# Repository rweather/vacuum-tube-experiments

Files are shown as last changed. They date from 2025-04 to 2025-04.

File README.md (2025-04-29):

Vacuum Tube Experiments
=======================

This repository collects up a number of experiments with making
vacuum tubes do interesting things at low voltage.

Many thanks to David Lovett a.k.a Usagi Electric for showing that it
was possible to operate vacuum tubes (or "valves" as we call them in
Australia) at low voltage and get useful work out of them.

## Blinky with two 6AU6 pentodes

The simplest thing to do with vacuum tubes is blink LED's!  Henri Abraham and
Eugene Bloch invented an
<a href="https://en.wikipedia.org/wiki/Multivibrator">astable multivibrator oscillator</a>
based on two triodes during World War I.
<a href="https://ik1zyw.blogspot.com/2022/01/abraham-bloch-valve-led-multivibrator.html">The author of this blog post</a>
showed how to make a simple Abraham-Bloch blinky that could operate down to
9V using the tubes they had available.

I adapted the circuit for two 6AU6's operating at 12V with the heaters
hooked up in series to give them 6V each.  That way I only needed a single
12V supply.  I added some blue LED's mounted underneath the tubes for extra
bling, but they are optional.

Here is the schematic (click for a PDF version):

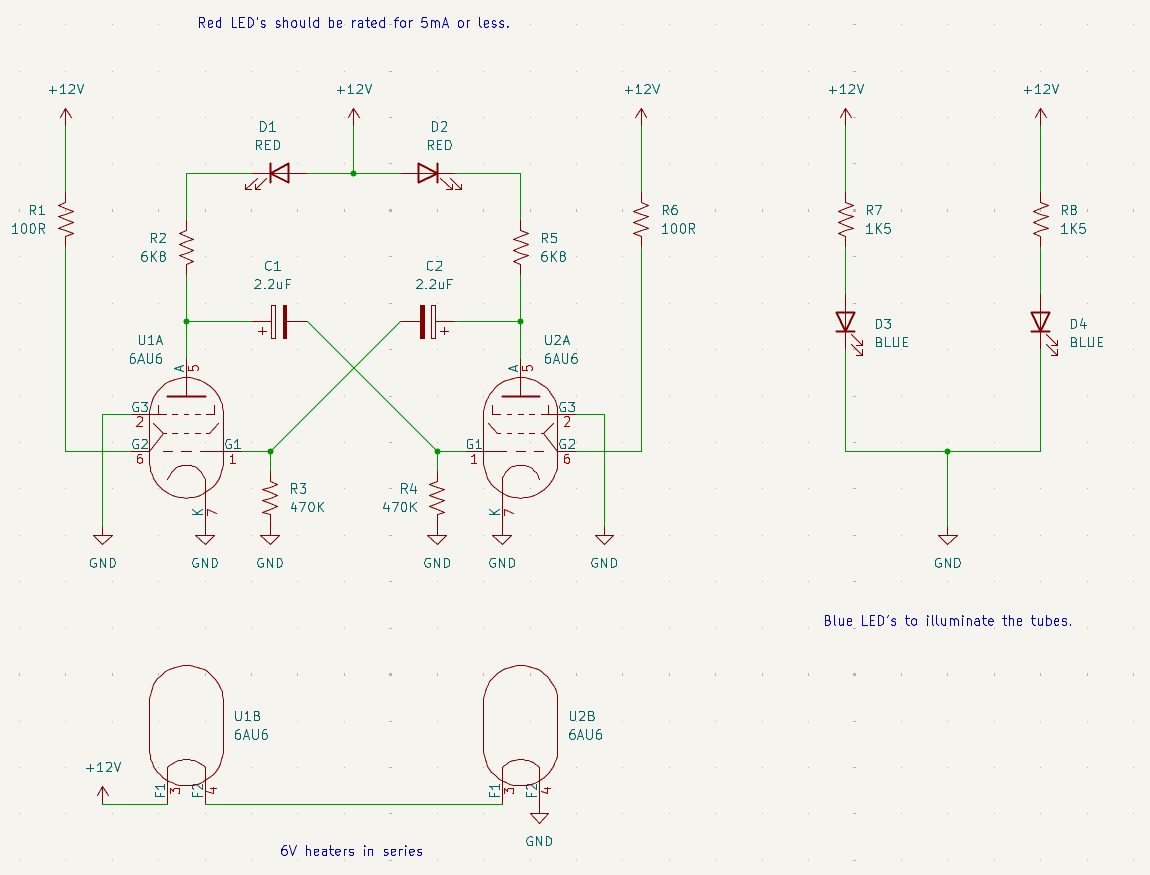
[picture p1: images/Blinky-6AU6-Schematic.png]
Blinky 6AU6 Schematic


Garden variety red LED's are rated for 15mA to 20mA and will be very dimly lit
with this circuit.  I recommend using red LED's that are rated for less than
5mA, ideally 2mA or less.

The period is about one second, spending half a second on each LED during the
blink cycle.  It takes about 5-10 seconds for the tubes to warm up, during
which time the LED's act a little weird.  It eventually sorts itself out.
The circuit is very sensitive - touching the components can change the blink
rate due to the impedance of the human body!

To adjust the blink rate, easiest is to change the value of C1 and C2 to
something higher or lower.  Alternatively, change R3 and R4.  Lower values
will blink faster.

I initially prototyped the circuit on a breadboard, and then soldered
up a real one on veroboard.  Here is what the real one looks like:

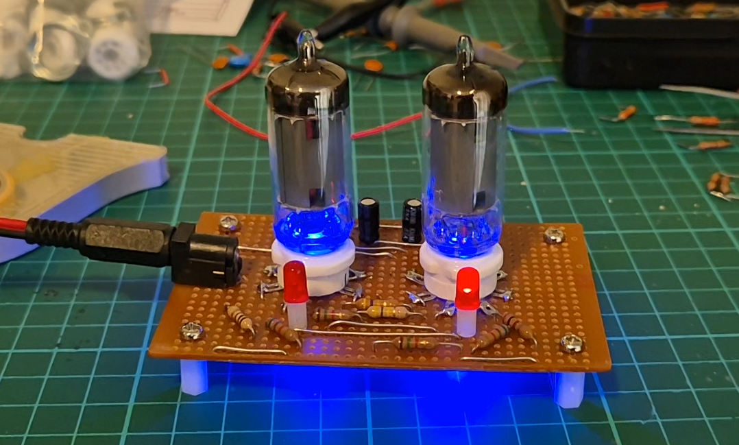
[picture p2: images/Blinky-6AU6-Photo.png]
Blinky 6AU6 Photo


## Blinky with a 6DJ8 dual triode

Can we do a blinky with one tube?  Yes we can!  The following schematic
uses a 6DJ8 dual triode (click for a PDF version):

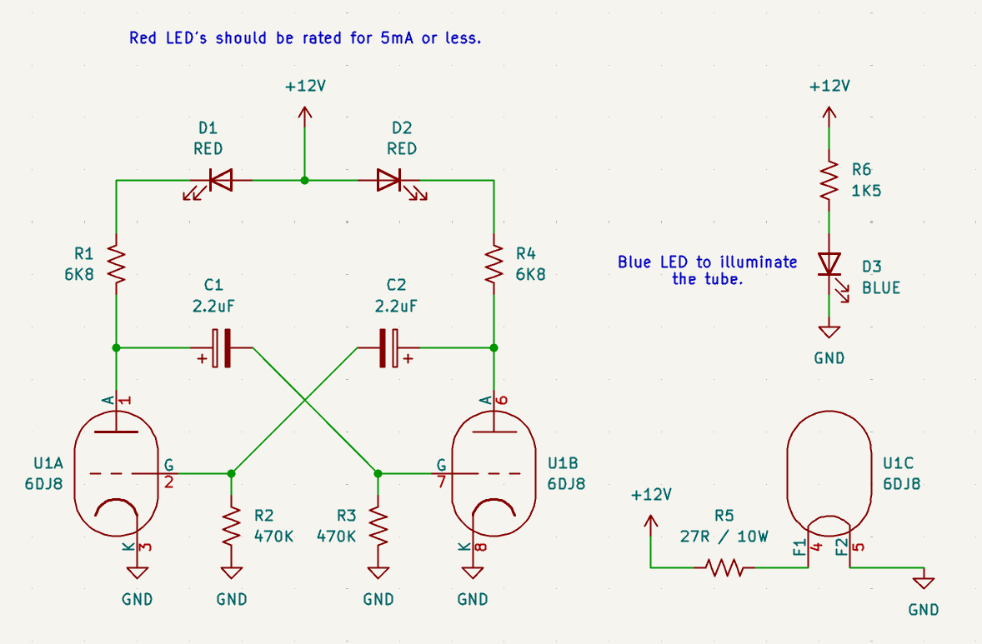
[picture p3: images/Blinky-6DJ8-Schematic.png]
Blinky 6DJ8 Schematic


Still runs off 12V.  I put a 27 ohm 10 watt resistor in series with the
heater to drop the heater voltage down to approximately 6V.  A high
wattage resistor is required because it will get very hot!

Here is what it looks like on a breadboard:

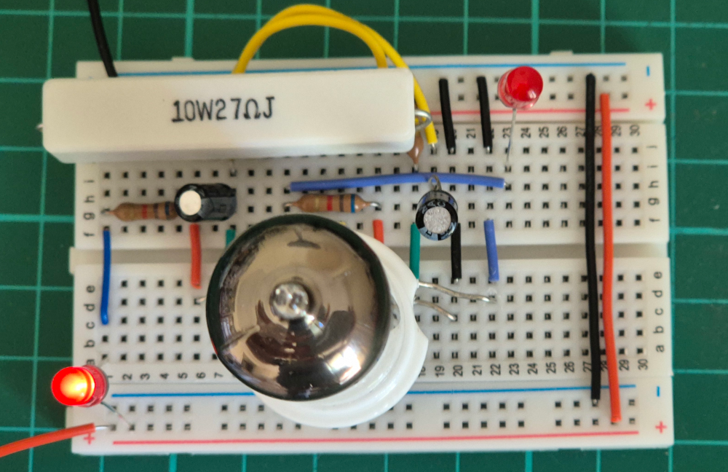
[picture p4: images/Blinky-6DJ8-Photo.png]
Blinky 6DJ8 Photo


A contributor on the Usagi Electric Discord server made up this same
circuit using a 12AX7 dual triode (12V heater) and it blinks!
For 12V heaters, remove the 10 watt resistor (R5) and run the heater
directly off the 12V supply.

## Characterising the frequency of the blinky

I played around with a number of capacitor and resistor values on the
6DJ8 version to get a faster oscillator and to see what the waveform
looked like.  With C1 = C2 = 100nF and R1 = R4 = 6.8K, R2 = R3 = 10K,
and the LED's removed, I got a frequency of around 449Hz on the two anodes:

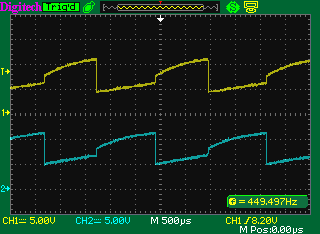
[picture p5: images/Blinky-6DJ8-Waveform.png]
Blinky 6DJ8 Waveform


The signal oscillates between about 4V and 11V, measured on the anodes.

With the LED's in-circuit the frequency was roughly 1 / (1.25 * RC) where
R = R1 + R2 (16.8K in my test circuit).  With the LED removed, the
frequency was closer to the ideal of 1 / (1.38 * RC) for astable
multivibrators.  Deviation between the ideal (431Hz) and measured
frequency (449Hz) was probably due to the 5% tolerance on the resistors
I was using.

## License

MIT License

## Contact

For more information on this project, to report bugs, or to suggest
improvements, please contact the author Rhys Weatherley via
[email](mailto:rhys.weatherley@gmail.com).

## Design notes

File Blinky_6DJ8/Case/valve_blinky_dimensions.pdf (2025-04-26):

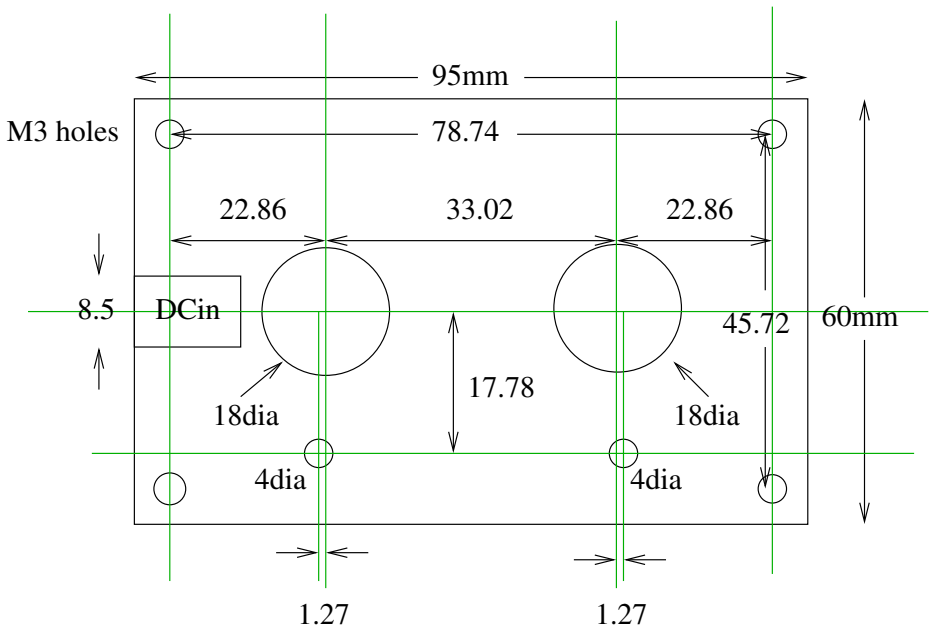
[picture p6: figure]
DCin8.5; 18dia; M3 holes; 4dia4dia

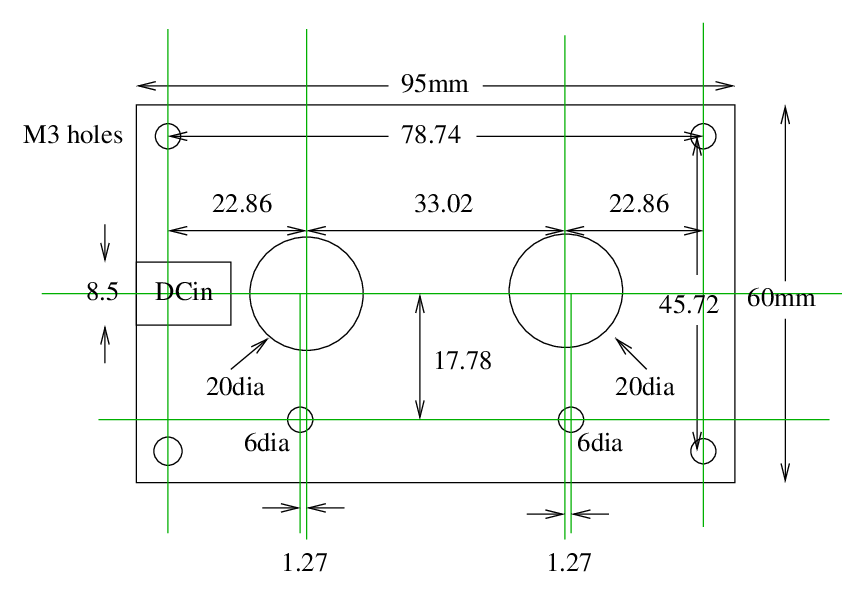
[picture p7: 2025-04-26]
Blinky_6DJ8/Case/valve_blinky_dimensions.png

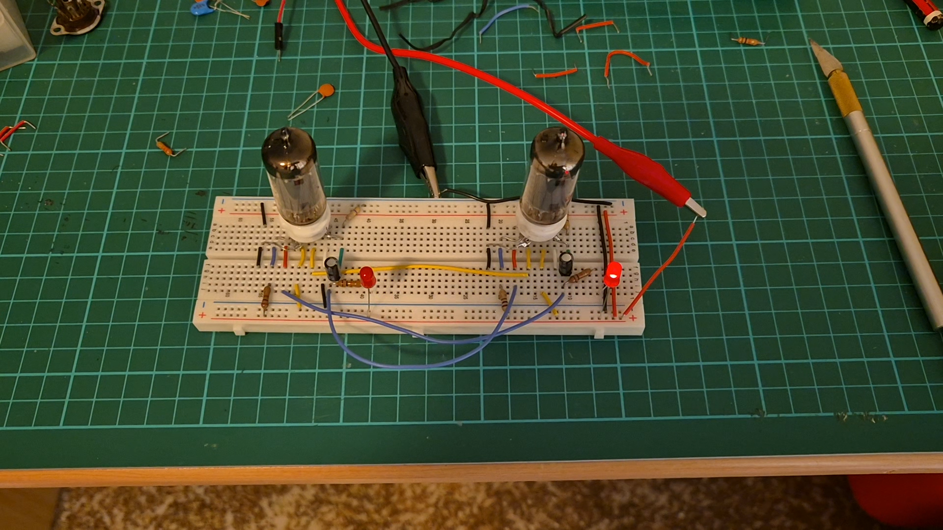
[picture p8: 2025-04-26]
Blinky_6DJ8/Case/Screenshot from 2025-04-26 11-38-58.png

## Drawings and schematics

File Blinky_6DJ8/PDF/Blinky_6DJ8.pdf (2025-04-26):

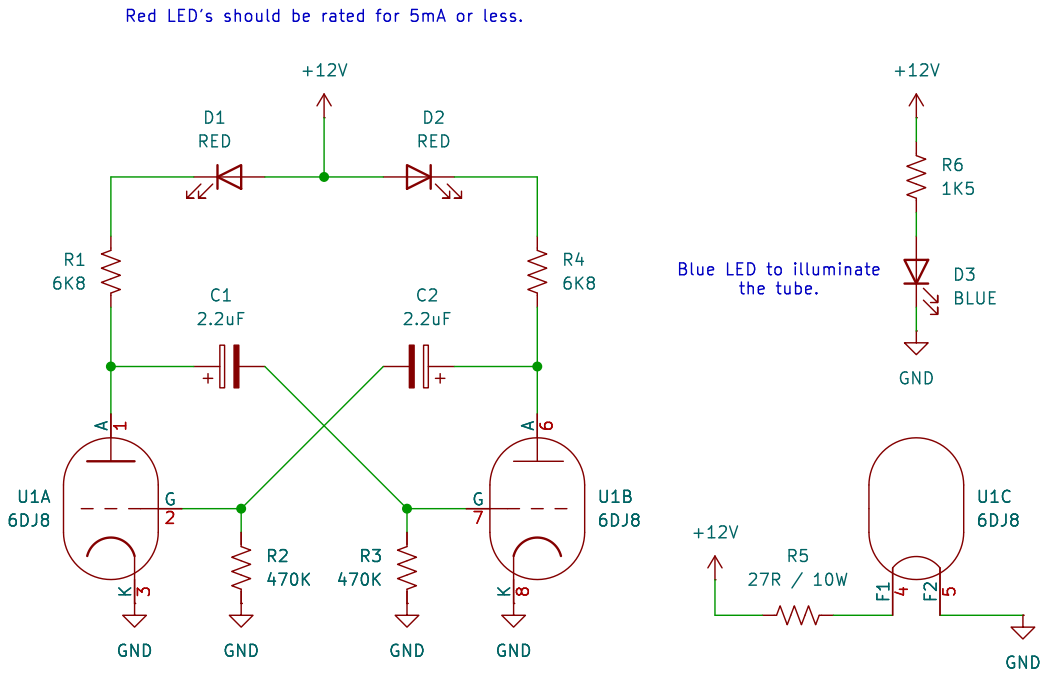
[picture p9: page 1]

the tube. Red LED's should be rated for 5mA or less.

Based on a design from here: https://ik1zyw.blogspot.com/2022/01/abraham-bloch-valve-led-multivibrator.html U1A

File: Blinky_6DJ8.kicad_sch Sheet: / Rhys Weatherley

Id: 1/1 Title: Blinky Using a 6DJ8 Dual Triode

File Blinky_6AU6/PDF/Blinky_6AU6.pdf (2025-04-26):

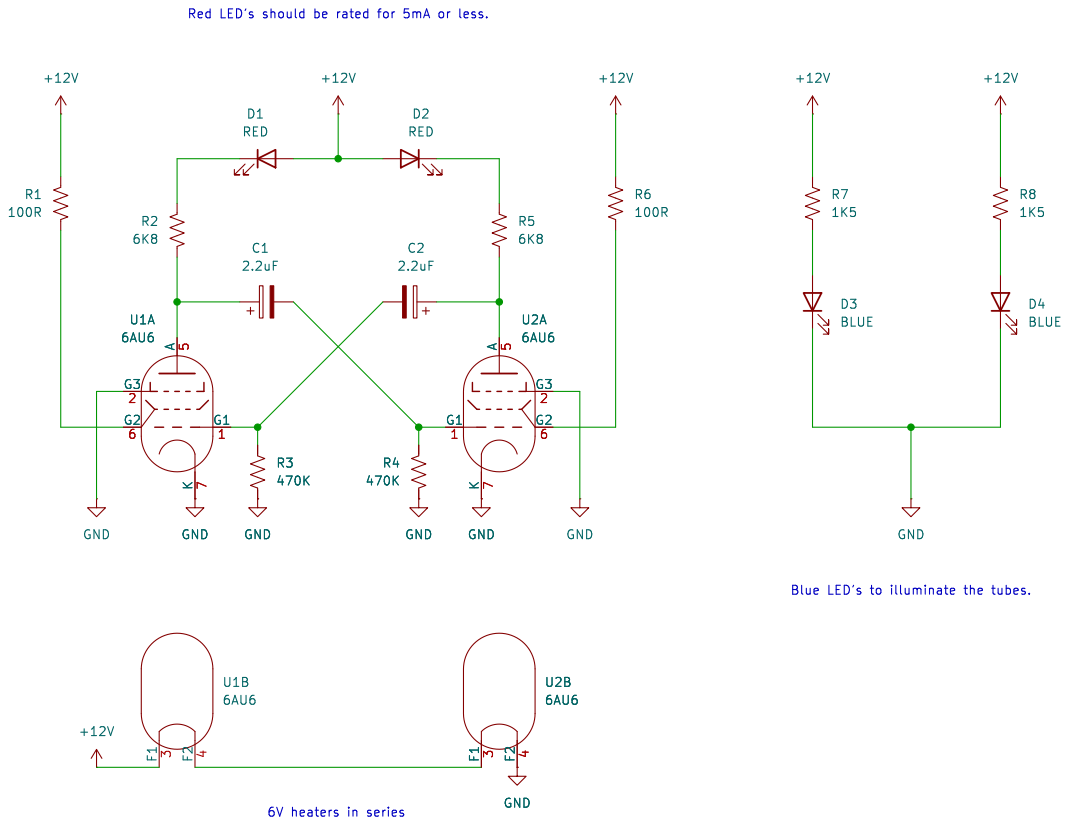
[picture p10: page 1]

File: Blinky_6AU6.kicad_sch Sheet: / Rhys Weatherley

Id: 1/1 Title: Blinky Using Two 6AU6 Pentodes

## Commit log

2025-04-26 Blinky using two 6AU6 Pentodes
    [Blinky_6AU6.kicad_pcb, Blinky_6AU6.kicad_sch]
2025-04-26 Blinky using a 6DJ8 dual triode
    [Blinky_6DJ8.kicad_pcb, Blinky_6DJ8.kicad_sch]
2025-04-28 Characterise the frequency of the blinky circuits
